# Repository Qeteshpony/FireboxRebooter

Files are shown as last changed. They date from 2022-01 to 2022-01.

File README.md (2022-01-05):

# FireboxRebooter
Rebooting a device that refuses to reboot

This piece of software, together with the hardware in this repository, allows automatic rebooting of a modified Watchguard Firebox M400 or M500 when the normal reboot doesn't work anymore. 

See https://electronics.qetesh.de/firebox-rebooter/ for details!

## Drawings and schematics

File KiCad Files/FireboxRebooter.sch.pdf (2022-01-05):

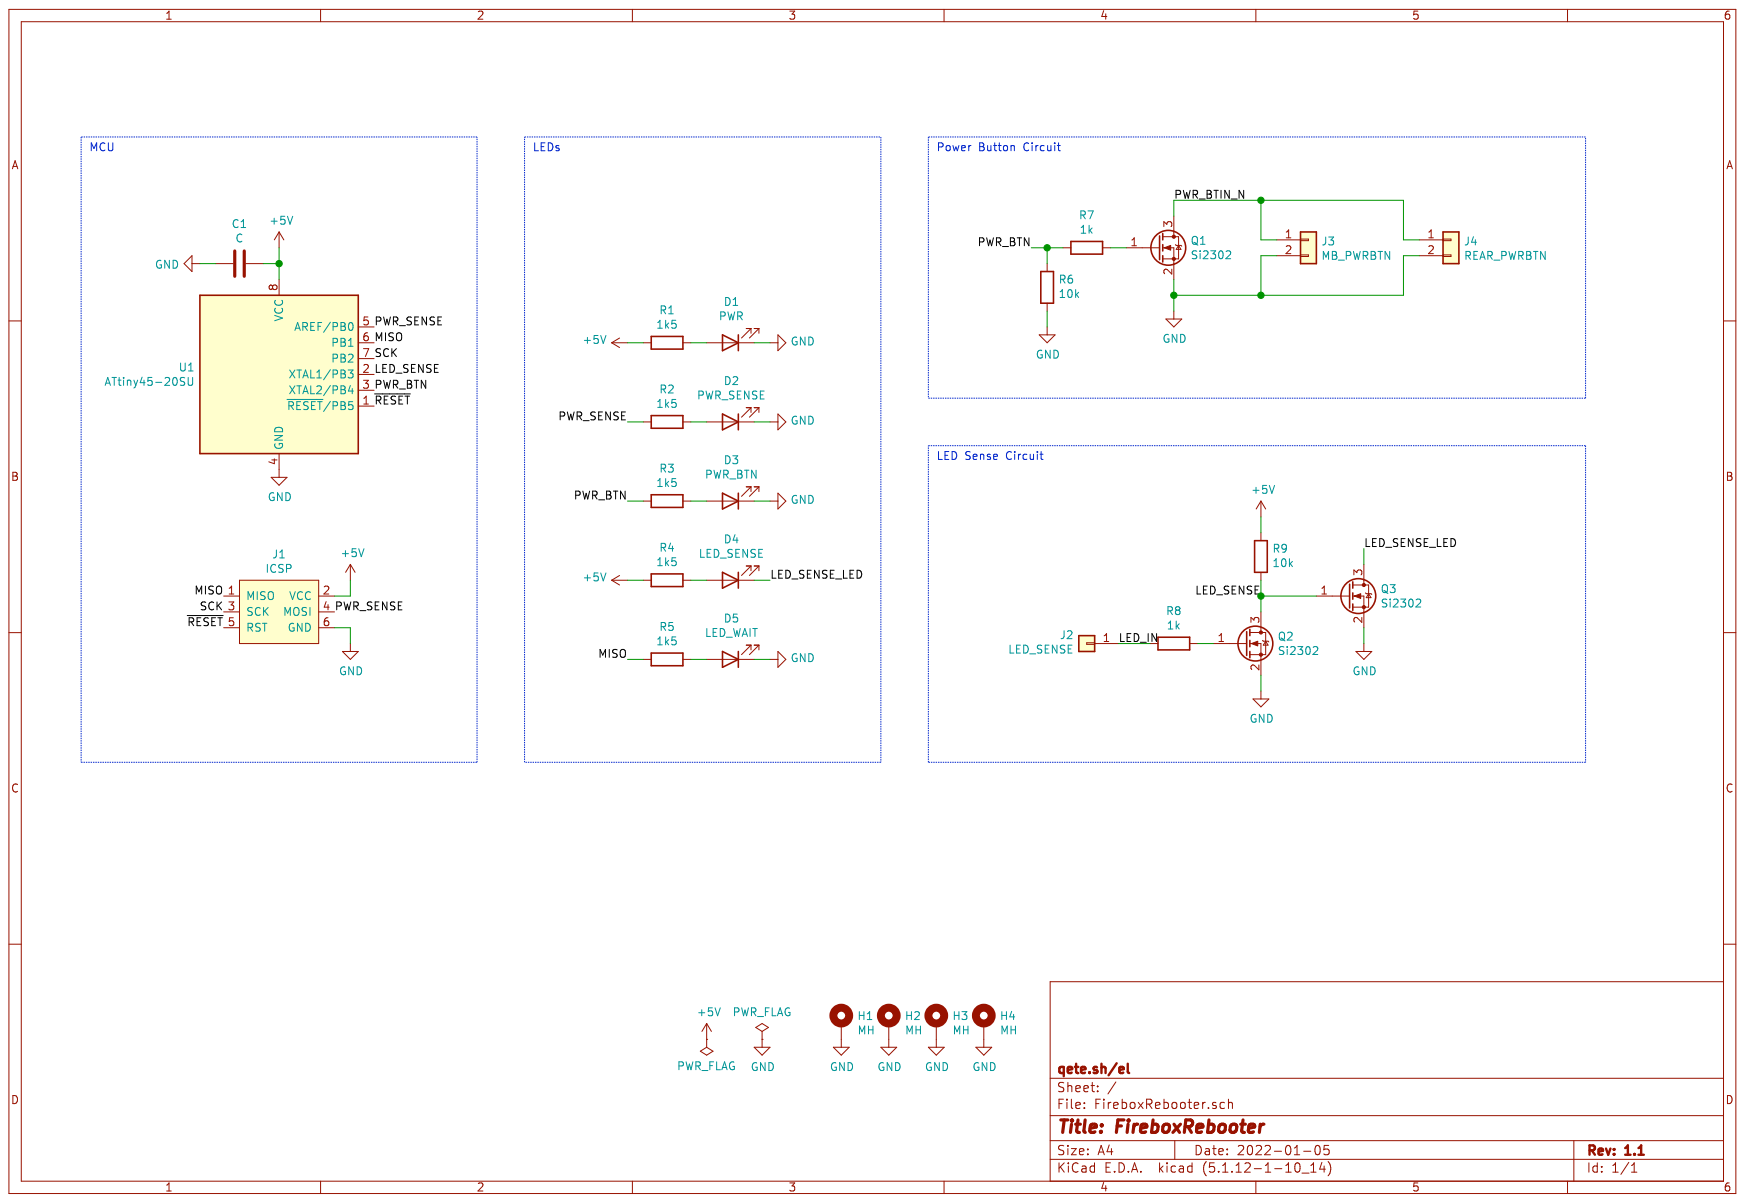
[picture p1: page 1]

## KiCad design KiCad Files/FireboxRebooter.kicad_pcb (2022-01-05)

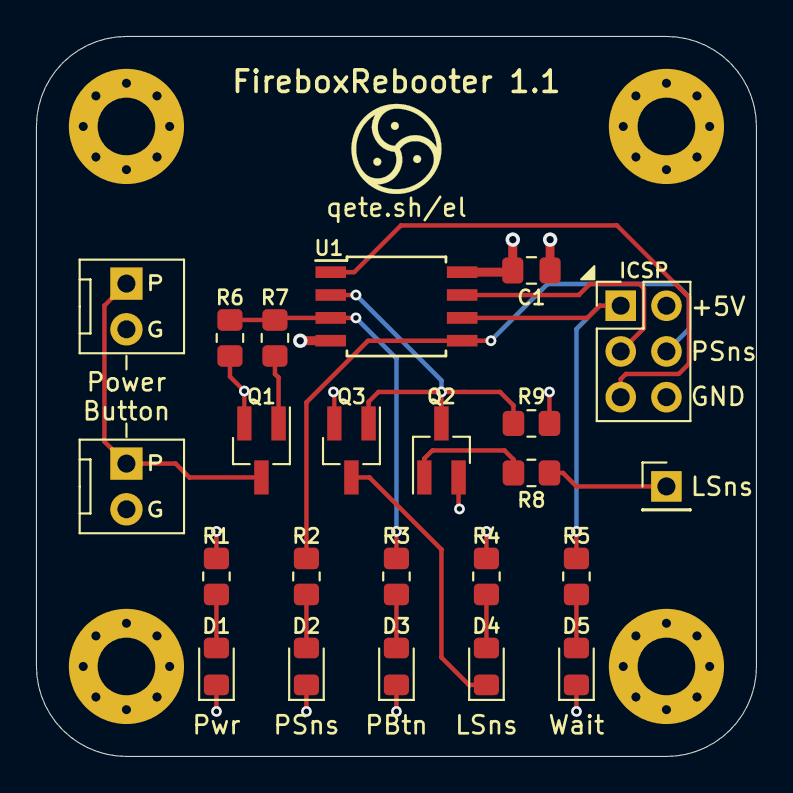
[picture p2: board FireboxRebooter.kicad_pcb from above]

Board: 4 copper layers, 40.0 x 40.0 mm, 27 parts (0 on the bottom side), 18 nets.

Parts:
C1: 100nF; C_0805_2012Metric_Pad1.18x1.45mm_HandSolder
D1: PWR; LED_0805_2012Metric_Pad1.15x1.40mm_HandSolder
D2: PWR_SENSE; LED_0805_2012Metric_Pad1.15x1.40mm_HandSolder
D3: PWR_BTN; LED_0805_2012Metric_Pad1.15x1.40mm_HandSolder
D4: LED_SENSE; LED_0805_2012Metric_Pad1.15x1.40mm_HandSolder
D5: LED_WAIT; LED_0805_2012Metric_Pad1.15x1.40mm_HandSolder
H1, H2, H3, H4: MH; MountingHole_3.2mm_M3_Pad_Via
J1: ICSP; PinHeader_2x03_P2.54mm_Vertical
J2: LED_SENSE; PinHeader_1x01_P2.54mm_Vertical
J3: MB_PWRBTN; Wurth_WR-WTB_2.54mm_2Pin
J4: REAR_PWRBTN; Wurth_WR-WTB_2.54mm_2Pin
Q1, Q2, Q3: Si2302; SOT-23_Handsoldering
R1, R2, R3, R4, R5: 1k5; R_0805_2012Metric_Pad1.20x1.40mm_HandSolder
R6, R9: 10k; R_0805_2012Metric_Pad1.20x1.40mm_HandSolder
R7, R8: 1k; R_0805_2012Metric_Pad1.20x1.40mm_HandSolder
U1: ATtiny45-20SU; SOIJ-8_5.3x5.3mm_P1.27mm

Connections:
+5V: C1.1, J1.2, R1.2, R4.2, R9.2, U1.8
/LED_IN: J2.1, R8.2
/LED_SENSE: Q2.3, Q3.1, R9.1, U1.2
/LED_SENSE_LED: D4.1, Q3.3
/MISO: J1.1, R5.2, U1.6
/PWR_BTIN_N: J3.1, J4.1, Q1.3
/PWR_BTN: R3.2, R6.2, R7.2, U1.3
/PWR_SENSE: J1.4, R2.2, U1.5
/SCK: J1.3, U1.7
/~RESET: J1.5, U1.1
GND: C1.2, D1.1, D2.1, D3.1, D5.1, H1.1, H2.1, H3.1, H4.1, J1.6, J3.2, J4.2, Q1.2, Q2.2, Q3.2, R6.1, U1.4
unnamed: D1.2, R1.1
unnamed: D2.2, R2.1
unnamed: D3.2, R3.1
unnamed: D4.2, R4.1
unnamed: D5.2, R5.1
unnamed: Q1.1, R7.1
unnamed: Q2.1, R8.1

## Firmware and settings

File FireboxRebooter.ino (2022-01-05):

/*
 * ATtinyCore - ATtiny 25/45/85 (No bootloader)
 * 
 * 
 */

// Pin definitions
#define PWRBTN   4
#define PWRSENSE 0
#define LEDSENSE 3
#define WAITLED  1
#define DBGPWM   2

// Timer Settings
#define RSTTIME  5000  // time in ms until a shutdown is forced when the SFP LED stays on
#define BOOTTIME 10000 // time in ms to wait after power on before going to sense mode again
#define OFFTIME  2000  // time in ms until reboot after shutdown
#define MAXHOLD  10000 // maximum time in ms that the power button is held

void setup() {
  pinMode(PWRBTN, OUTPUT);
  digitalWrite(PWRBTN, LOW);
  pinMode(WAITLED, OUTPUT);
  digitalWrite(WAITLED, LOW);
  pinMode(PWRSENSE, INPUT);
  pinMode(LEDSENSE, INPUT);

  // wait for power being turned on before doing anything at all
  bootWait();
}

bool ledstate;
unsigned long int ledtime; 
unsigned long int seconds;

void loop() {
  // check if power is on, if not go to waiting state
  if (digitalRead(PWRSENSE) == LOW) bootWait();

  // check sense LED state
  bool ledsense = digitalRead(LEDSENSE);
  if (ledsense != ledstate) {
    ledstate = ledsense;
    if (ledsense == HIGH) ledtime = millis(); // store the time of LED turning on
  }
  if (ledstate == HIGH && ledtime + RSTTIME <= millis()) FBReset(); // start reset cycle when LED is on for more than RSTTIME ms
  
  // flash wait LED once every other second to show standby
  if (seconds + 2000 <= millis()) {
    seconds = millis();
    digitalWrite(WAITLED, HIGH);
    delay(5);
    digitalWrite(WAITLED, LOW);
  }
}

void bootWait() {
  // Wait for power being turned on
  while (digitalRead(PWRSENSE) == LOW) { 
    //digitalWrite(WAITLED, !digitalRead(WAITLED)); // toggle pin to flash LED
    PINB = 1 << WAITLED; // toggle pin to flash LED
    delay(500); 
  }

  // wait for POST being finished before starting the loop
  digitalWrite(WAITLED, HIGH);
  
  // make sure the box isnt switched off while waiting for the sense led to go off
  unsigned long int timer = millis();
  while (digitalRead(PWRSENSE) == HIGH && (timer + BOOTTIME > millis() || digitalRead(LEDSENSE) == HIGH)); //do nothing
  
  digitalWrite(WAITLED, LOW);
  
  // if power is off at this point, start bootWait again (This only happens when box was switched off while waiting)
  if (digitalRead(PWRSENSE) == LOW) bootWait();
}

void FBReset() {  
  // Switch Firebox off 
  switchPower(LOW); 
  
  // pause 'OFFTIME' ms
  digitalWrite(WAITLED, HIGH);
  delay(OFFTIME);
  digitalWrite(WAITLED, LOW);
  
  // Switch Firebox on again and wait BOOTTIME ms
  switchPower(HIGH); 

  bootWait();
}

void switchPower(bool power) {
  // press and hold power button
  digitalWrite(PWRBTN, HIGH); 
  
  // wait until either power is switched or MAXHOLD time is up
  unsigned long int timestamp = millis();
  while (digitalRead(PWRSENSE) != power && timestamp + MAXHOLD > millis()) {
    PINB = 1 << WAITLED; // toggle pin
    delay(200); 
  }

  // release power button
  digitalWrite(PWRBTN, LOW);


}

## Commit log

2022-01-05 Add KiCad Files
    [FireboxRebooter.kicad_pcb, FireboxRebooter.sch]
2022-01-05 Hardware Version 1.1
    Fixed a little mistake
    [FireboxRebooter.kicad_pcb, FireboxRebooter.sch]
